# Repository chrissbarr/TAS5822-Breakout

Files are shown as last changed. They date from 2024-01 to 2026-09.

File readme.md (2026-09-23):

# TAS5822 Breakout Board
An easy-to-use breakout board for the TI TAS5822 I2S audio DAC.

The TAS5822 is a stereo Class-D digital audio amplifier with I2S audio input and I2C control. It can drive 4/6/8 Ohm speakers at up to 35W.

The TAS5822 is compatible with digital audio sources that can stream data in the I2S format. This includes popular microcontroller families such as ESP32, STM32, or some single-board computers such as the Raspberry Pi.

This breakout board is an easy way to add high-quality digital audio to an embedded project.

An Arduino library that implements control of the TAS5822 via I2C is available [here](https://github.com/chrissbarr/TAS5822-Arduino-Library).

An example of playing audio over Bluetooth using an ESP32 is available [here](./Firmware/ESP32_Bluetooth_Example/).

The TAS5822M Breakout Board is available for purchase [here](https://aus3d.com.au/products/tas5822m-breakout-board).

## Images
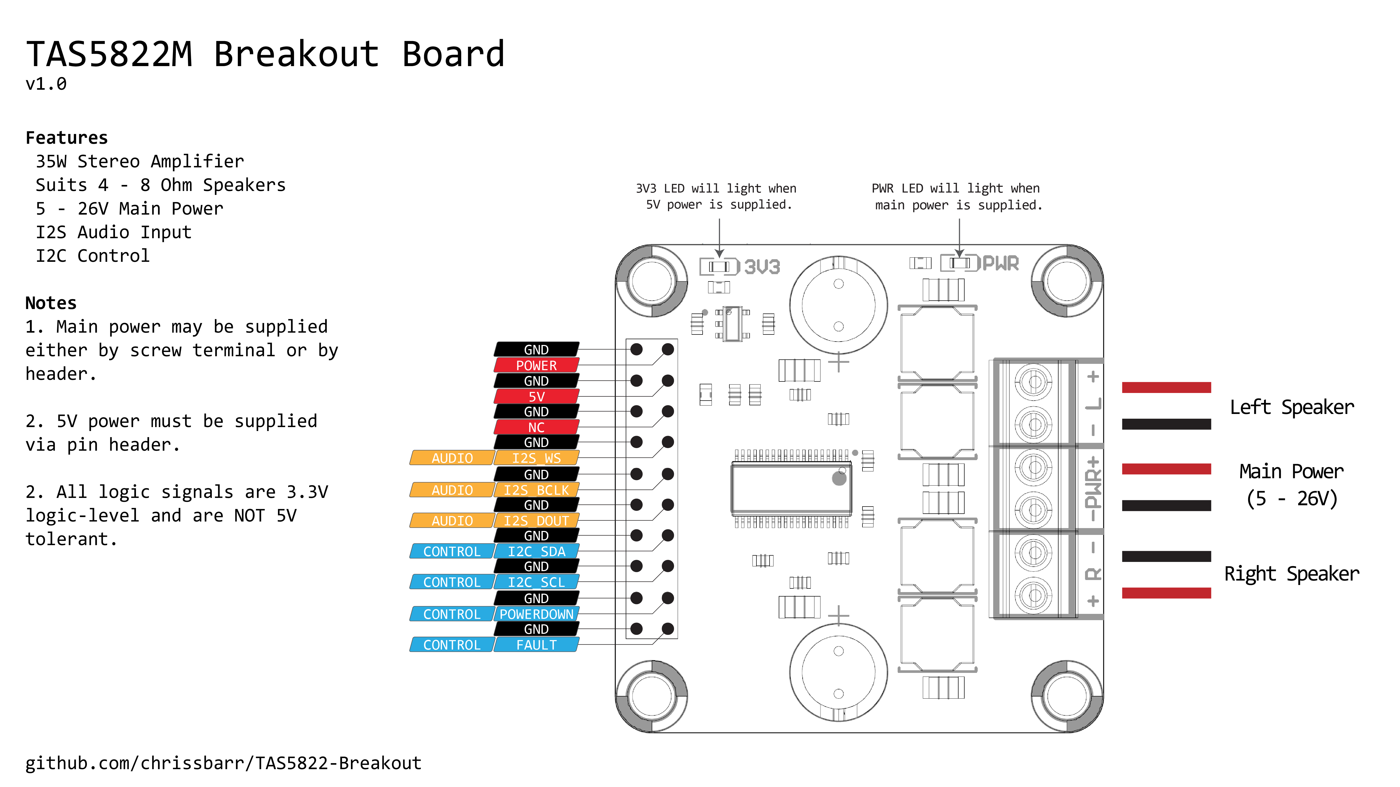
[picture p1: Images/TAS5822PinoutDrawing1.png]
Pinout Drawing

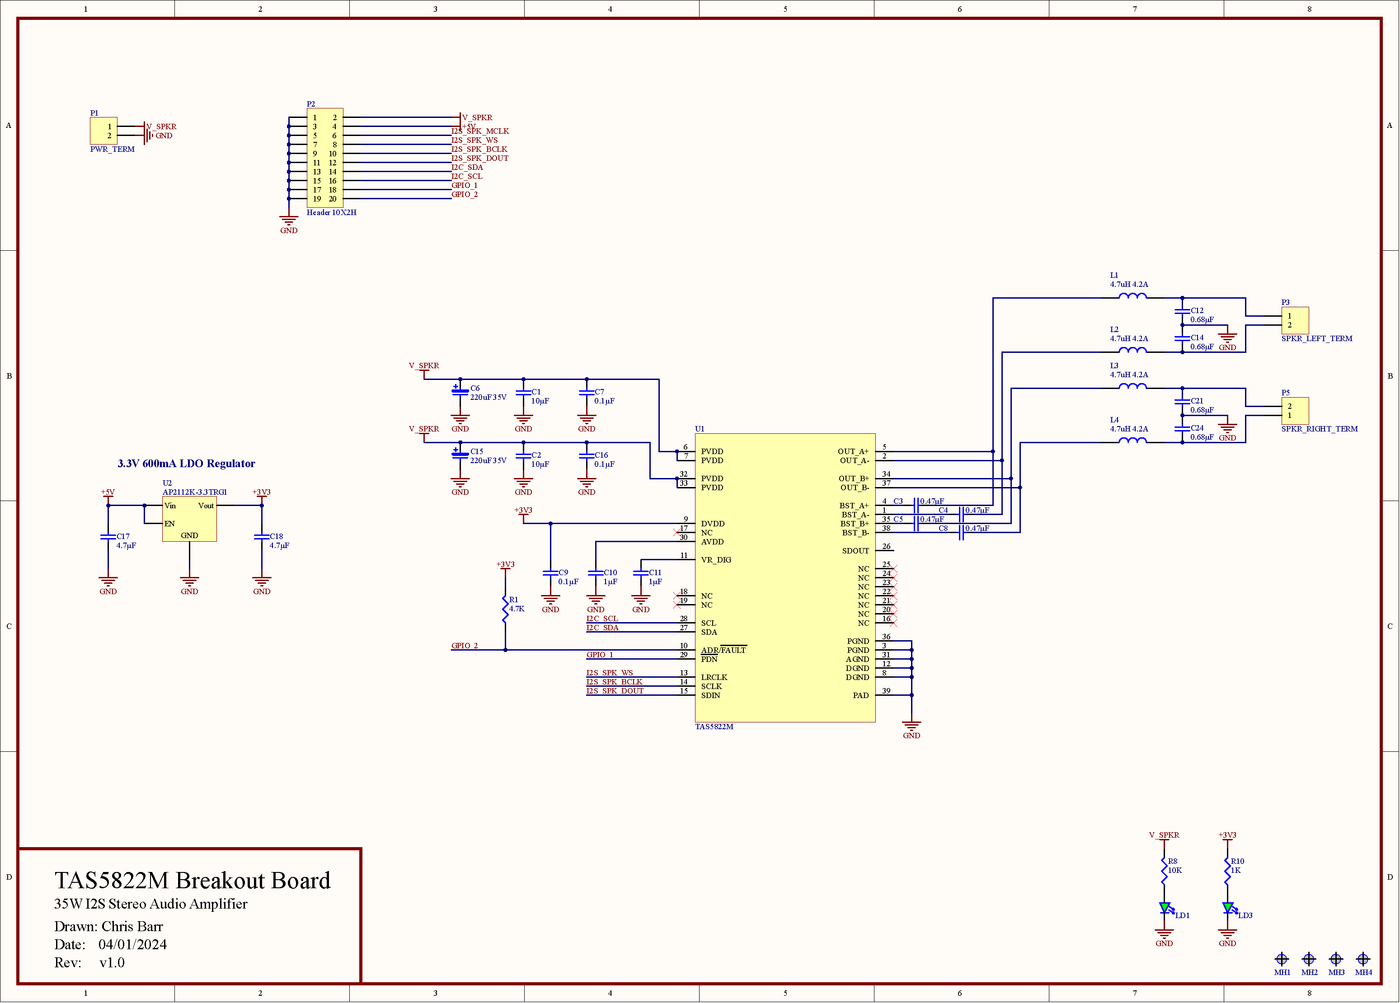
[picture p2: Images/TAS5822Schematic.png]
Schematic


## Pinout
| Pin | Description | Notes |
| --- | --- | --- |
| P1-1 | Main Power | 5 - 26V Power Input. This is the also connected to pin header P2-2. Provide main power through either P2 or P1. It is not necessary to use both. |
| P1-2 | GND | |
| P3-1 | Left Speaker + | |
| P3-2 | Left Speaker - | |
| P5-1 | Right Speaker - | |
| P5-2 | Right Speaker + | |
| P2-1,3,5,7,9,11,13,15,17,19 | GND | Multiple ground pins are provided to simplify wiring and to allow good signal integrity. All of these pins are connected together. It is not typically required to connect them all. |
| P2-2 | Main Power | 5 - 26V Power Input. This is the also connected to screw terminal P1. Provide main power through either P2 or P1. It is not necessary to use both. |
| P2-4 | 5V Power | 5V Power Input. Can be 4.3V - 6.0V. Regulated down to 3.3V internally to power TAS5822M. |
| P2-6 | NC | Not connected. Reserved for future use. |
| P2-8 | I2S_WS | I2S Word Select. Also called left-right clock (LRCLK) or frame sync (FS). 3.3V logic level. |
| P2-10 | I2S_BCLK | I2S Bit Clock. Also called serial clock (SCLK). 3.3V logic level. |
| P2-12 | I2S_DIN | I2S Data In. 3.3V logic level. |
| P2-14 | I2C_SDA | I2C Serial Data. Pullup to 3.3V is required on host board. 3.3V logic level. |
| P2-16 | I2C_SCL | I2C Serial Clock. Pullup to 3.3V is required on host board. 3.3V logic level. |
| P2-18 | PDN | TAS5822 Power Down Input. Driving this signal low will shutdown the TAS5822M. Must be driven high to enable operation. 3.3V logic level. |
| P2-20 | ADR/FLT | TAS5822 Address / Fault. Resistor R1 between ADR and 3.3V sets I2C address. Replace R1 to change I2C address if required. This signal can also be monitored to detect faults. Refer to TAS5822 datasheet. 3.3V logic level. |

## References
* [TAS5822 Arduino Library](https://github.com/chrissbarr/TAS5822-Arduino-Library)
* [ESP32 A2DP Bluetooth Example](./Firmware/ESP32_Bluetooth_Example/)
* [TI TAS5822 Details](https://www.ti.com/product/TAS5822M)
* [Purchase](https://aus3d.com.au/products/tas5822m-breakout-board)

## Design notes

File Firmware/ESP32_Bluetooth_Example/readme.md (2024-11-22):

# TAS5822 ESP32 A2DP Example
This example is intended for the ESP32.

This is an example of a basic Bluetooth A2DP audio receiver, streaming audio to the TAS5822 I2S amplifier.

The ESP32-A2DP library (https://github.com/pschatzmann/ESP32-A2DP) is used to configure audio streaming.

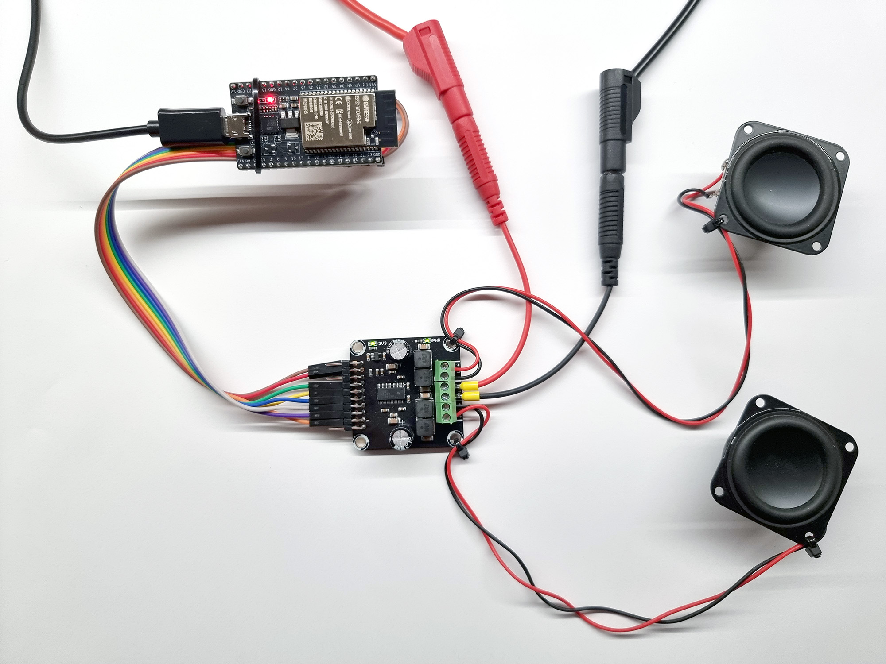
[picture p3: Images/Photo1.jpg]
ESP32 Pinout


## Required Hardware
* ESP32 Board (original, not ESP32-S2/S3 etc., as we need Bluetooth audio support)
* TAS5822M Breakout Board
* 12V Power Supply
* 2x 4/6/8 Ohm Speakers

## Software Setup
This folder is a PlatformIO firmware project. Open this folder using PlatformIO, and check that you can compile successfully.

Upload the compiled firmware to the ESP32 board.

## Hardware Setup
These instructions are written to suit an ESP32 DevKitC V4, with pinout as shown below. Different boards may have different pinouts that require some adjustment. Some pin mappings may be adjusted in the firmware if desired.

Reference ESP32 pinout:
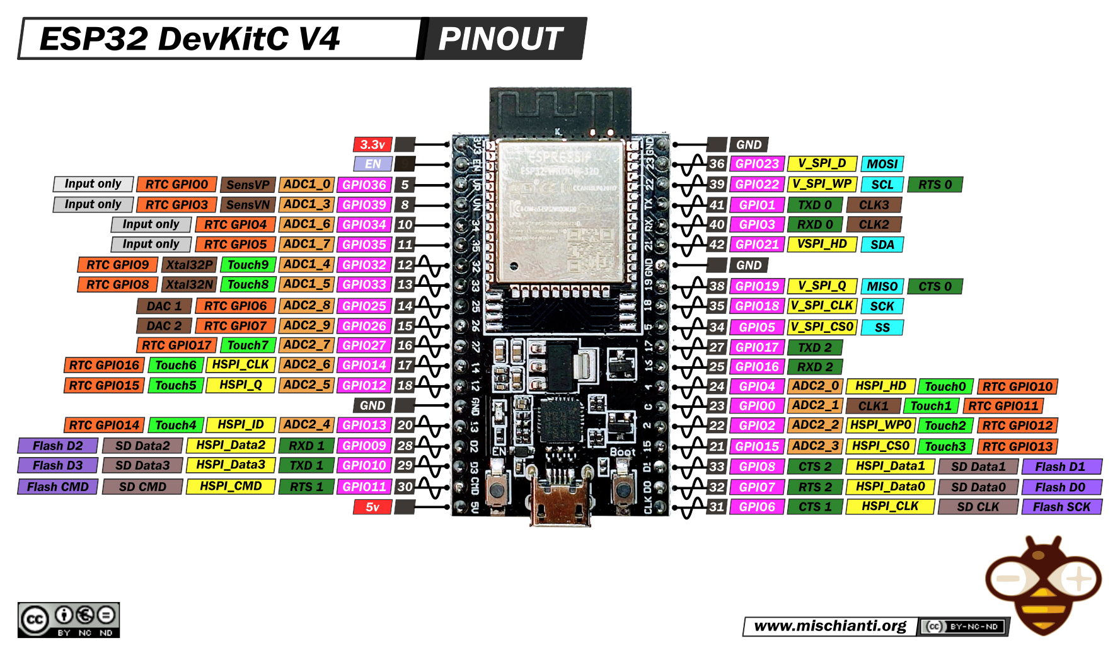
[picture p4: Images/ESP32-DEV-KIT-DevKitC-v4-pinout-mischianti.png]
Pinout Drawing ESP32 Pinout


Reference TAS5822 pinout:
Pinout Drawing

Connect the ESP32 and TAS5822 boards as follows:

* ESP32 5V -> TAS5822 5V
* ESP32 GND -> TAS5822 GND
* ESP32 I2C SDA (IO21) -> TAS5822 I2C_SDA
* ESP32 I2C SCL (IO22) -> TAS5822 I2C_SCL
* ESP32 I2S Word Select (IO33) -> TAS5822 I2S_WS
* ESP32 I2S Bit Clock (IO27) -> TAS5822 I2S_BCLK
* ESP32 I2S Data Out (IO32) -> TAS5822 I2S_DIN
* ESP32 (IO13) -> TAS5822 PDN

Connect the speakers to the two speaker terminals on the TAS5822 board.

Connect the TAS5822 to 12V power, either via the screw terminal or the pin header. If you are first testing the board, it is recommended to use an adjustable current-limited power supply in case of wiring mistakes. 

## Recommended Steps

Make all connections as described above.

Supply 5V power to the ESP32 board (via USB or otherwise). Check that the TAS5822 3V3 LED is lit, indicating that the 5V power from the ESP32 is received and regulated down to 3.3V as required.

Enable the 12V power supply to the TAS5822 board. Check that the TAS5822 PWR LED is lit, indicating the 12V power is being received.

Compile and upload the firmware to the ESP32 board.

Once the firmware is running, the ESP32 will present as a Bluetooth audio device. Connect to it from a suitable device (phone, laptop, etc.). Play audio and check that the speakers work as expected.

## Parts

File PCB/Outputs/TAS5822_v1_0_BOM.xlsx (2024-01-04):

Designator | Description | Quantity | Note | Manufacturer 1 | Manufacturer Part Number 1 | Supplier 1 | Supplier Part Number 1
U1 | 35-W, INDUCTOR-LESS, DIGITAL INP | 1 |  | Texas Instruments | TAS5822MDCPR | Digi-Key | 296-TAS5822MDCPRCT-ND
C6, C15 | CAP ALUM 220UF 20% 35V RADIAL | 2 | Approved sub OK | Wurth Electronics | 860020574012 | Digi-Key | 732-8946-1-ND
C7, C9, C16 | CAP CER 0.1UF 50V X7R 0603 | 3 | Approved sub OK | Taiyo Yuden | UMJ107BB7104KAHT | Digi-Key | 587-4474-1-ND
C3, C4, C5, C8 | CAP CER 0.47UF 35V X7R 0603 | 4 | Approved sub OK | Taiyo Yuden | GMJ107BB7474KAHT | Digi-Key | 587-4355-1-ND
C12, C14, C21, C24 | CAP CER 0.68UF 100V X7R 1206 | 4 | Approved sub OK | TDK | C3216X7R2A684K160AA | Digi-Key | 445-14810-1-ND
C10, C11 | CAP CER 1UF 35V X5R 0603 | 2 | Approved sub OK | Taiyo Yuden | GMK107BJ105KAHT | Digi-Key | 587-3358-1-ND
C17, C18 | CAP CER 4.7UF 16V X5R 0603 | 2 | Approved sub OK | TDK | C1608X5R1C475K080AC | Digi-Key | 445-7478-1-ND
C1, C2 | CAP CER 10UF 35V X5R 1206 | 2 | Approved sub OK | Taiyo Yuden | GMK316BBJ106MLHT | Digi-Key | 587-4898-1-ND
L1, L2, L3, L4 | FIXED IND 4.7UH 4.2A 35 MOHM SMD | 4 |  | TDK | VLS6045EX-4R7M | Digi-Key | 445-173055-1-ND
P2 | Header, 10-Pin, Dual row, Right Angle | 1 | Approved sub OK | Generic Header
U2 | IC REG LINEAR 3.3V 600MA SOT25 | 1 |  | Diodes | AP2112K-3.3TRG1 | Digi-Key | AP2112K-3.3TRG1DICT-ND
LD1, LD3 | LED GREEN CLEAR CHIP SMD 0603 | 2 | Approved sub OK | Vishay Lite-On | LTSTC190KGKT | Digi-Key | 160-1435-2-ND
R10 | RES SMD 1K OHM 1% 1/10W 0603 | 1 | Approved sub OK | Yageo | RC0603FR-071KL | Digi-Key | 311-1.00KHRCT-ND
R1 | RES SMD 4.7K OHM 1% 1/10W 0603 | 1 | Approved sub OK | Yageo | RC0603FR-074K7L | Digi-Key | 311-4.70KHRCT-ND
R8 | RES SMD 10K OHM 1% 1/10W 0603 | 1 | Approved sub OK | Yageo | RC0603FR-0710KL | Digi-Key | 311-10.0KHRCT-ND

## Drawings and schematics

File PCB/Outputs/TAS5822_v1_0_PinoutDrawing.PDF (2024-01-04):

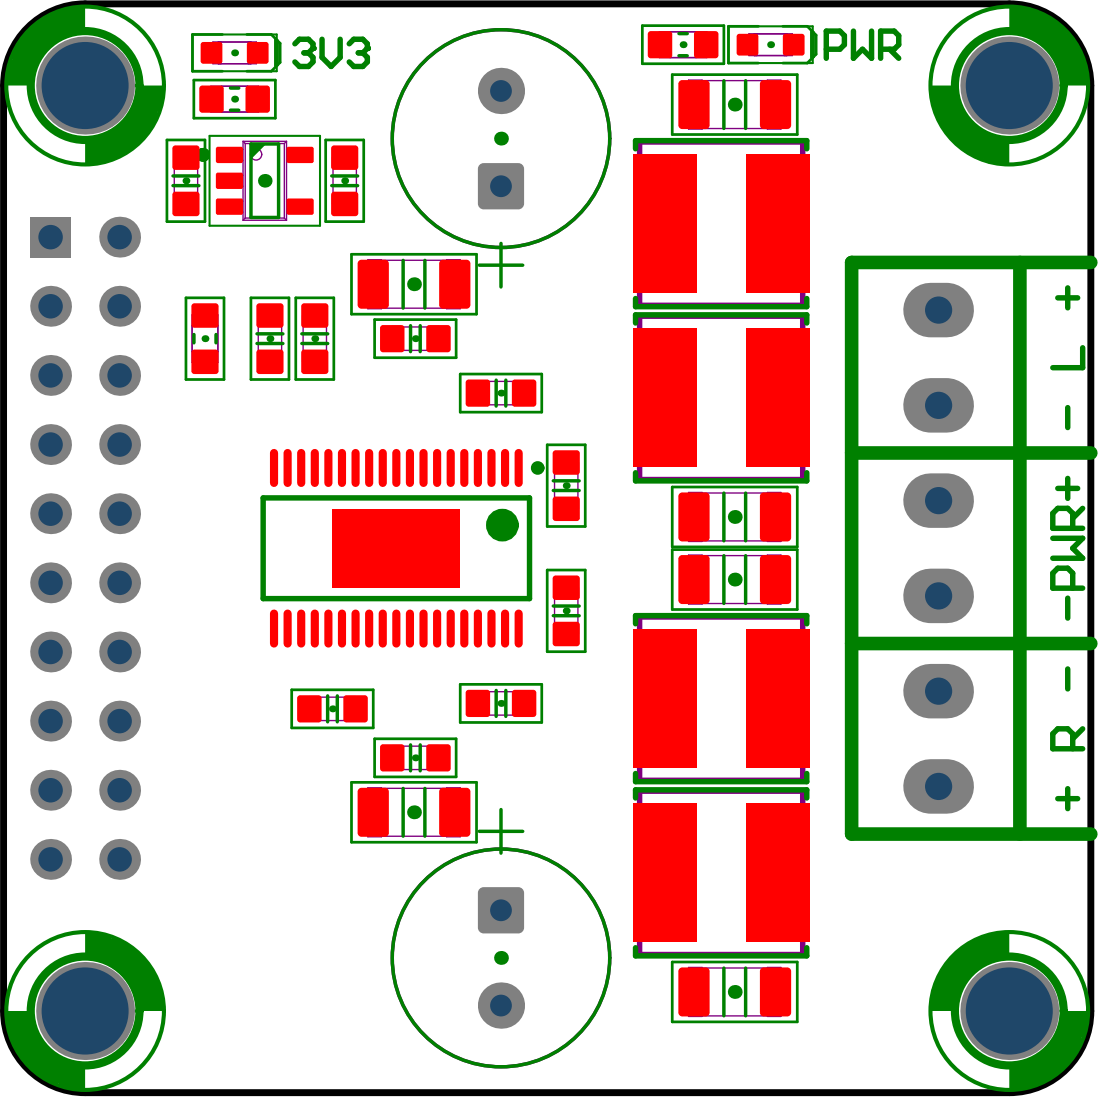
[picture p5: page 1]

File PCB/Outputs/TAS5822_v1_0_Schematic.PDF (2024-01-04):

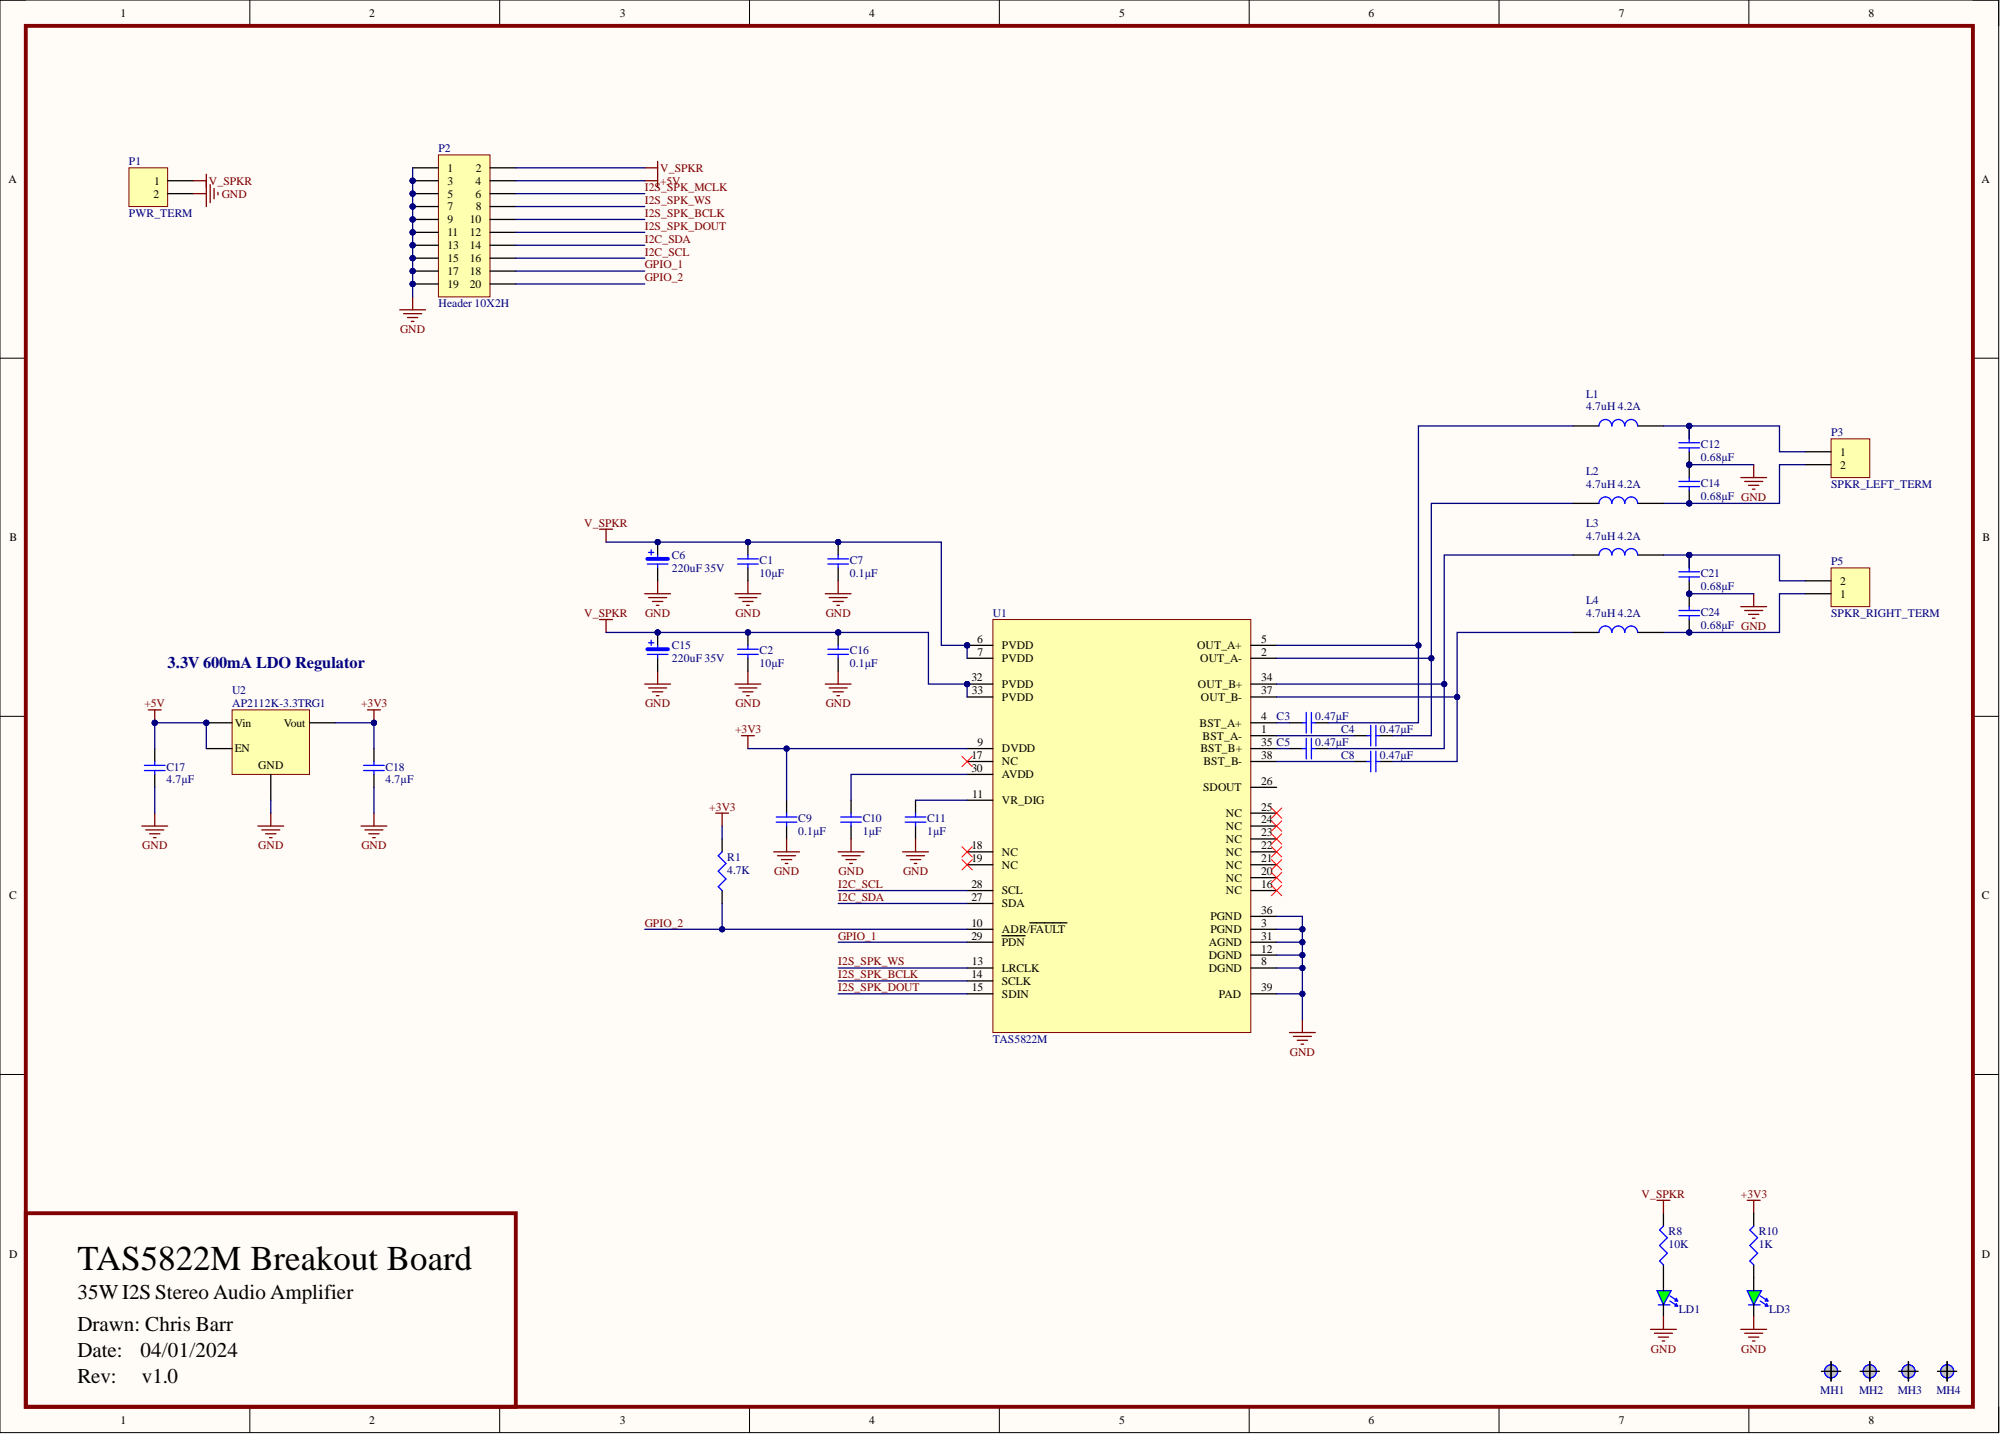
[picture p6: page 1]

1 | | C4 | 0.4 | 7 µ F
3 5 C5 | 0.4 | 7 µ F

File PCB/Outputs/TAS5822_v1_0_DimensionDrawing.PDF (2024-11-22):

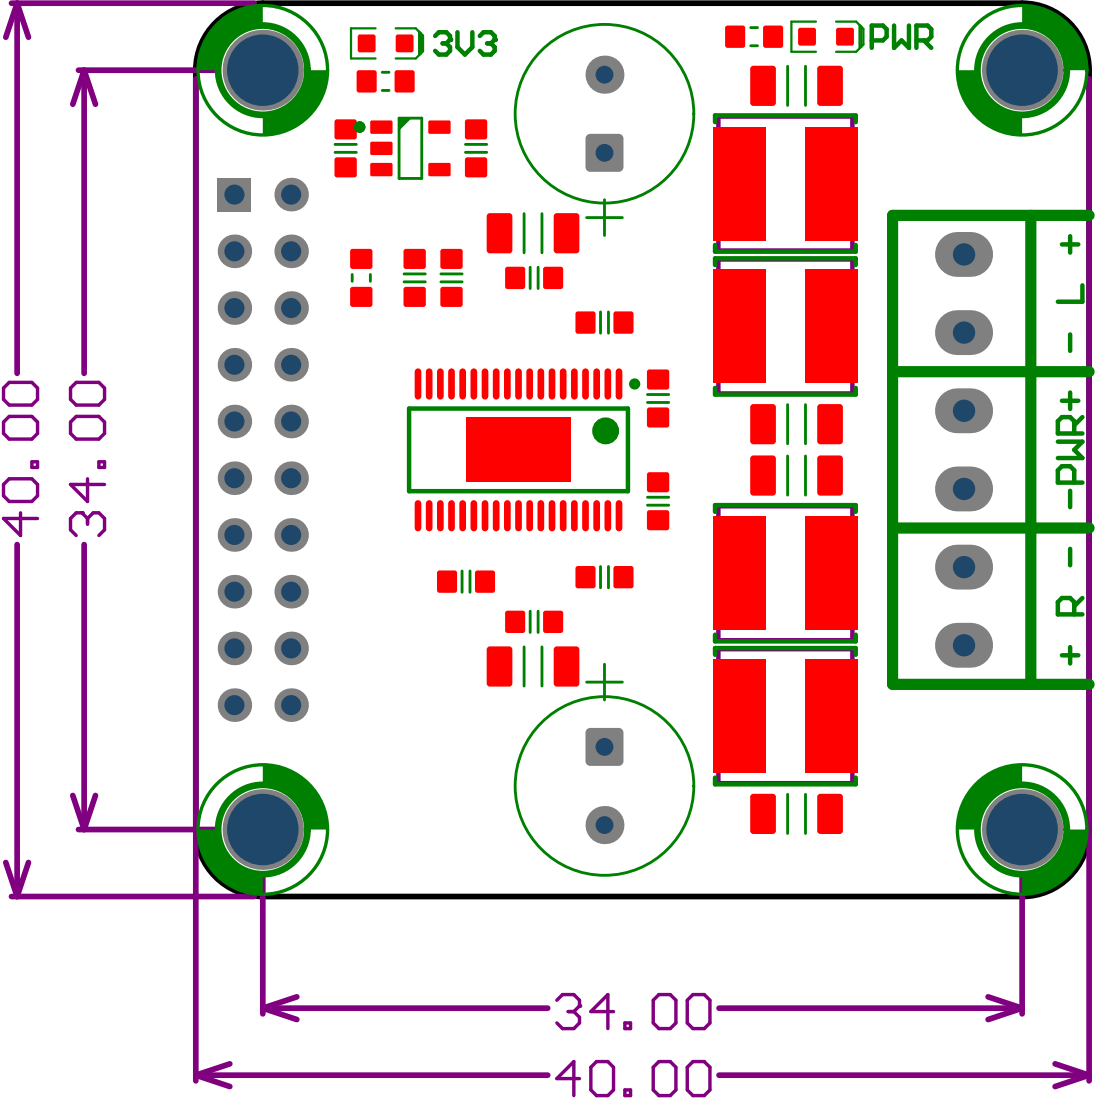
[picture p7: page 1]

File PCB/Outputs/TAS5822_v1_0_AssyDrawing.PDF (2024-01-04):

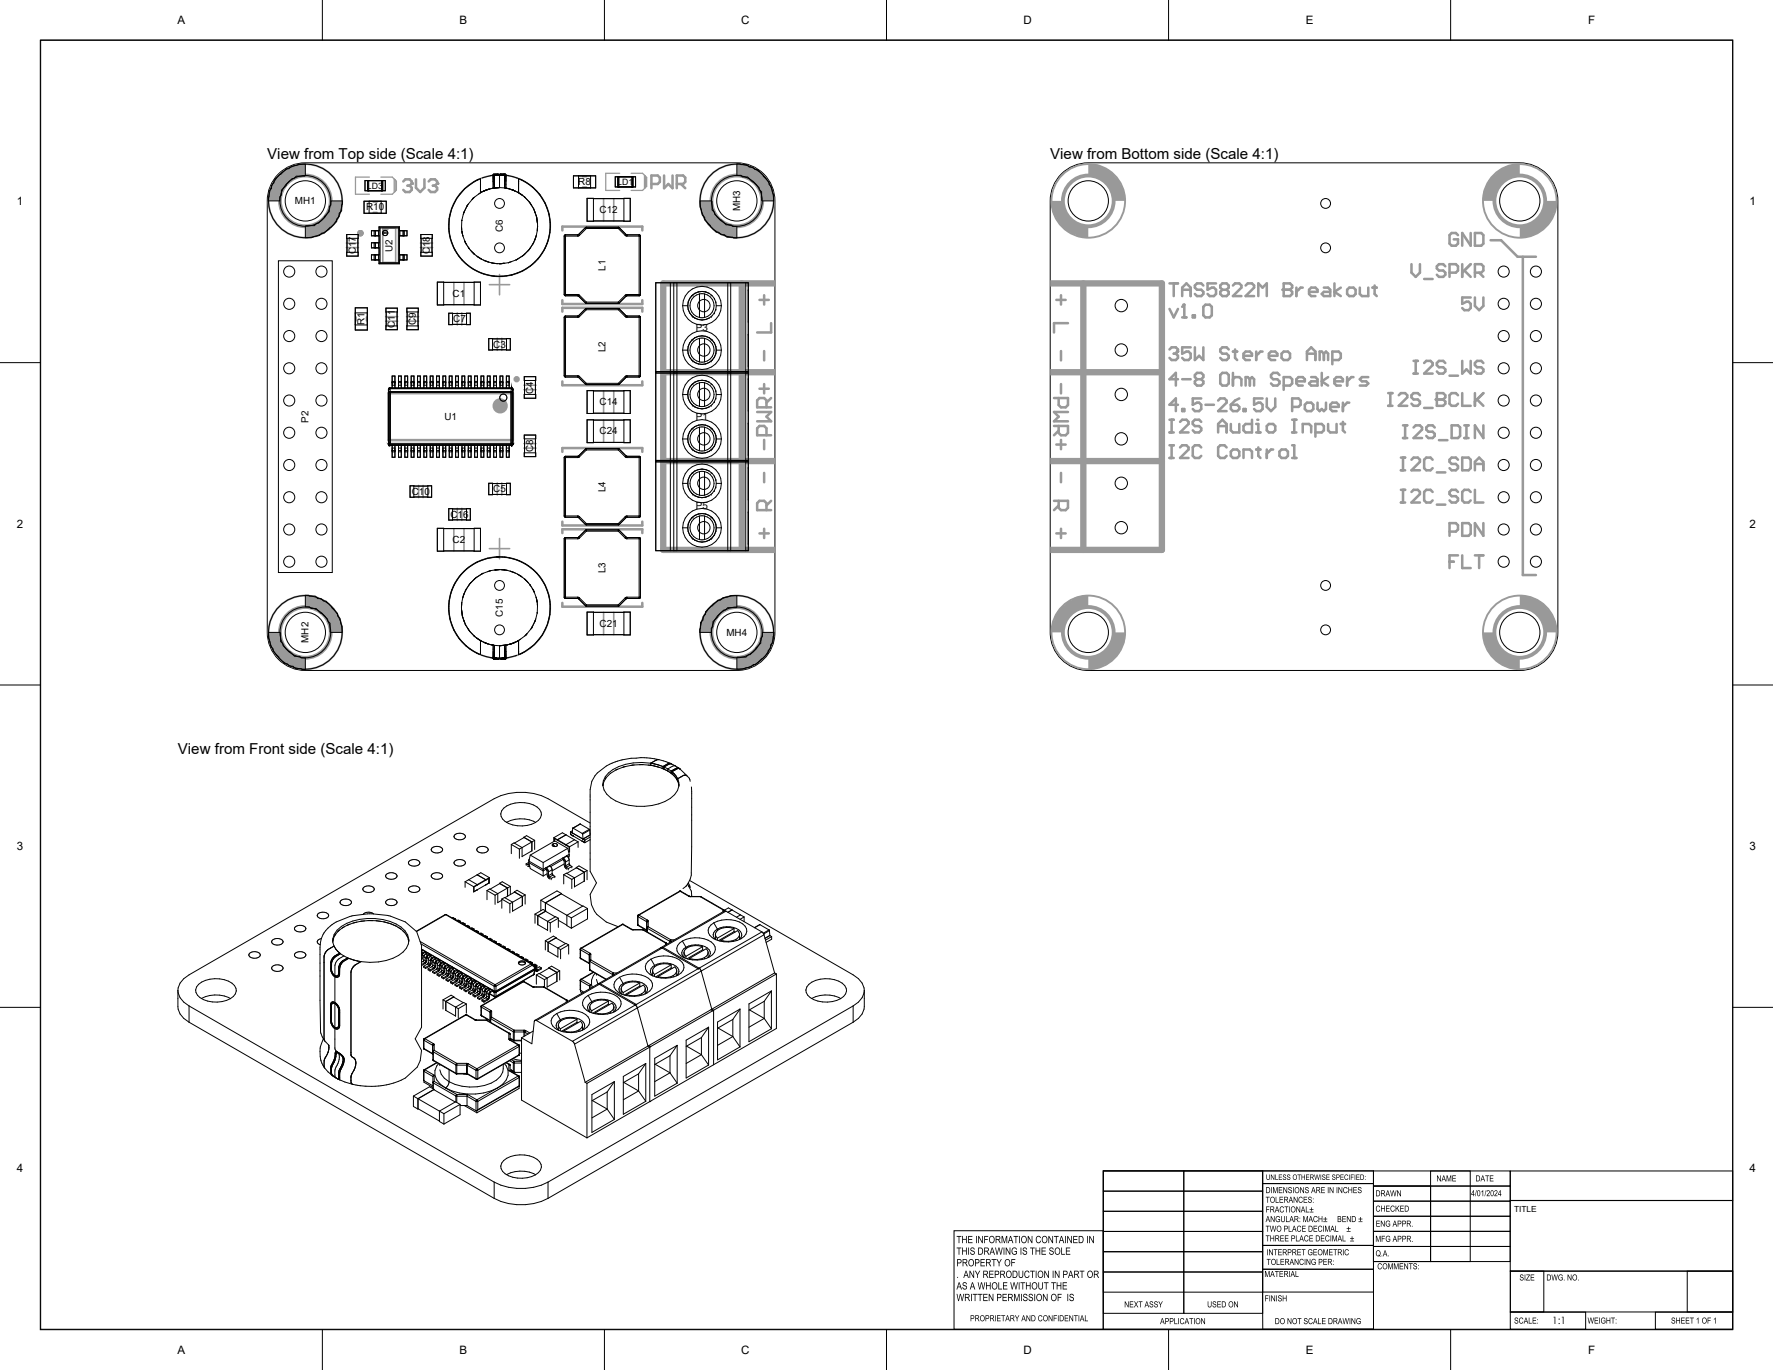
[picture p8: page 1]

View from Front side (Scale 4:1)

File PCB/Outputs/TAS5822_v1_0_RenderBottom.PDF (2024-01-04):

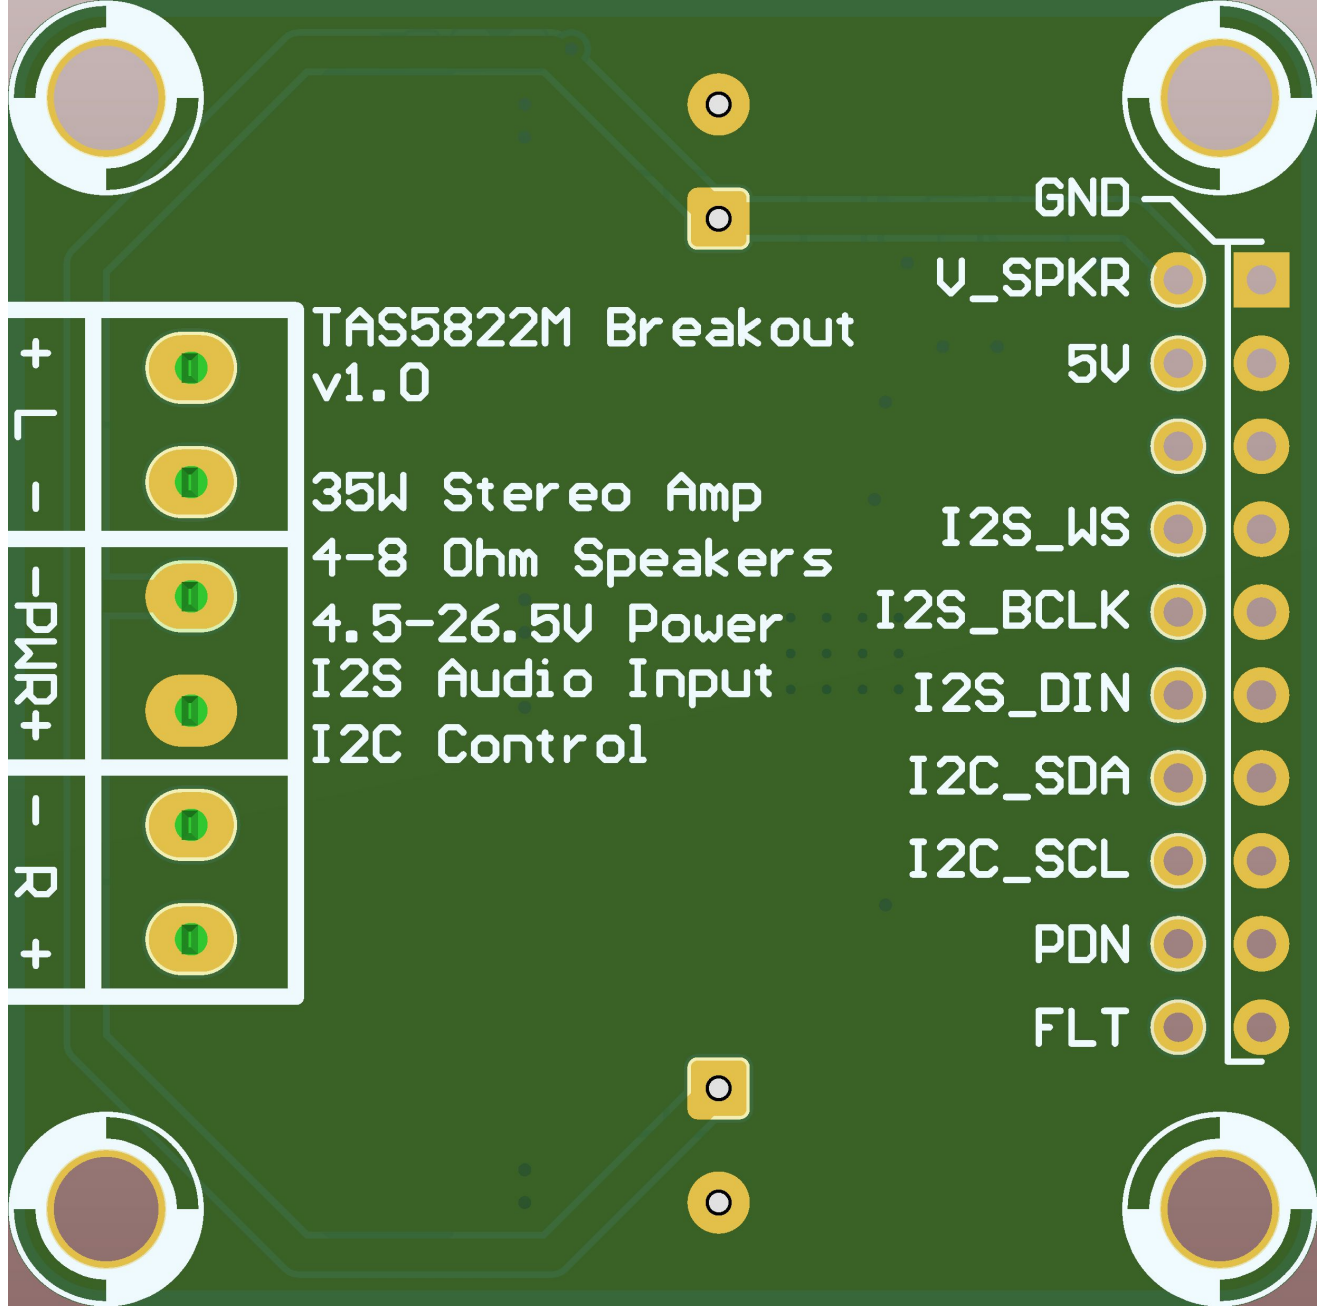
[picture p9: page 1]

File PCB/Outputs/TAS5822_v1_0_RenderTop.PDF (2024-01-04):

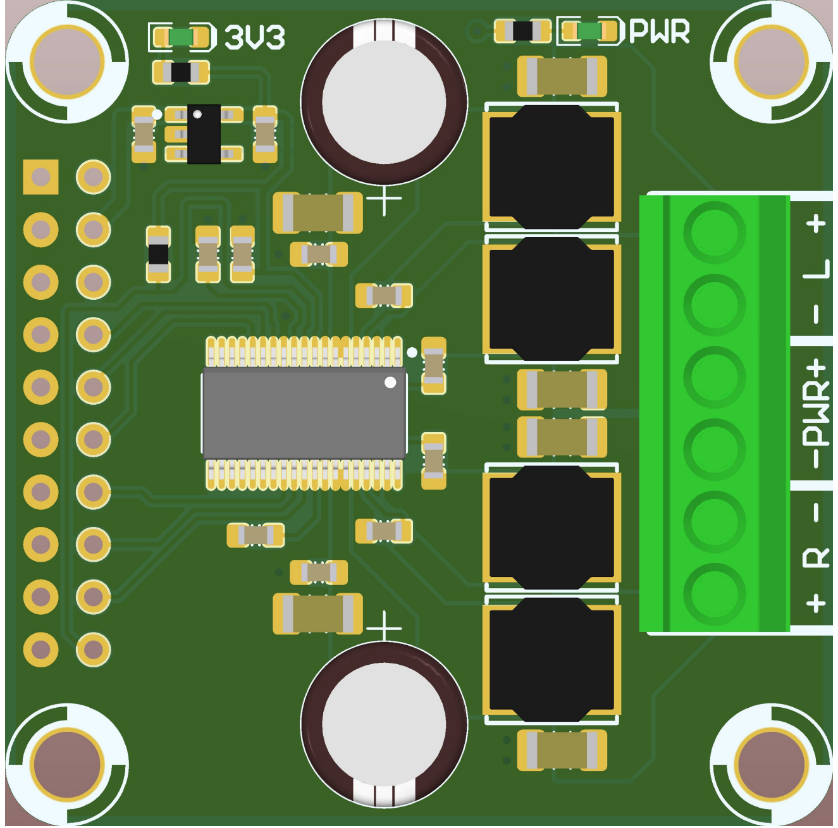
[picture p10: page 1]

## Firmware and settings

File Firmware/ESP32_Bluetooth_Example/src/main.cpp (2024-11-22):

/*
This example is intended for the ESP32.

This is an example of a basic Bluetooth A2DP audio receiver, streaming audio to the TAS5822 I2S amplifier.

The ESP32-A2DP library (https://github.com/pschatzmann/ESP32-A2DP) is used to configure audio streaming.
*/

// Library Includes
#include "TAS5822.h"

// ESP32-A2DP Library
#include "BluetoothA2DPSink.h"

// Arduino Core
#include <Arduino.h>
#include <Wire.h>

/* Pin connected to TAS5822 PDN pin */
constexpr int16_t pdnPin = 13;

/* I2C Address of TAS5822 */
constexpr uint8_t i2cAddr = 44;

TAS5822::TAS5822<TwoWire> tas5822(Wire, i2cAddr, pdnPin);

/* Set ESP32 I2S Pinout */
i2s_pin_config_t pin_config = {
    .mck_io_num = I2S_PIN_NO_CHANGE,
    .bck_io_num = 27,
    .ws_io_num = 33,
    .data_out_num = 32,
    .data_in_num = I2S_PIN_NO_CHANGE};

/* Construct BT A2DP Sink */
BluetoothA2DPSink a2dp_sink;

void setup() {
    Serial.begin(115200);
    Serial.println("Start setup...");

    /* Uncomment to enable debug logging to Serial */
    // tas5822.setLoggingOutput(&Serial);

    /* Create Audio Sink first, so that I2S interface is active. */
    a2dp_sink.set_pin_config(pin_config);
    a2dp_sink.start("Example-Music");

    /* Enable internal pullup resistors on I2C signals
    This is not ideal, external pullups should be used!
    However this is sufficient for basic testing. */
    pinMode(21, INPUT_PULLUP);
    pinMode(22, INPUT_PULLUP);

    /* TAS5822 should be started AFTER I2S interface (above). */
    if (!tas5822.begin()) {
        Serial.println("Error! TAS5822 initialisation failed!");
        while (true) {}
    }
    /* Set Volume */
    tas5822.setAnalogGain(-16);
    /* Set Format */
    tas5822.setAudioFormat(TAS5822::DATA_FORMAT::I2S);
    tas5822.setAudioWordLength(TAS5822::DATA_WORD_LENGTH::b16);
    /* Un-Mute */
    tas5822.setMuted(false);

    Serial.println("Setup finished!");
}

void loop() {
    /* Nothing to do */
    delay(100);
}

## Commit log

2024-01-04 Initial design work
    [TAS5822.PcbDoc, TAS5822.PrjPCB, TAS5822.SchDoc]
2024-01-04 Generate v1.0 outputs
    [TAS5822_v1_0_BOM.xlsx, TAS5822_v1_0_PickPlace.csv]
2024-11-22 Add and generate dimension drawing
    [TAS5822.PcbDoc]
2026-09-23 Fix ADR/FLT pin number in pinout table (P2-20, not P2-18)
